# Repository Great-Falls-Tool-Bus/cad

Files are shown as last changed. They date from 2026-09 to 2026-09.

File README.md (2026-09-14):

# cad

GFTB shelving and related CAD drawings for the Great Falls Tool Bus.

## Layout

Follows the [VoronUsers](https://github.com/VoronDesign/VoronUsers) mods layout: one directory per creator, one per mod, each self-describing.

```
bus_mods/<creator>/<mod>/
├─ .metadata.yml     title, description, file manifest
├─ README.md         what it is, materials, images
├─ CAD/              source (.f3d) and neutral (.step) exports
├─ images/           renderings
├─ docs/             build sheets — LaTeX sources, compiled by Bazel
└─ pdfs/             the compiled build sheets, checked in so nobody needs a toolchain to read them
```

Index: [`bus_mods/README.md`](bus_mods/README.md).

## Building documents

Documents are LaTeX compiled with [rules_tectonic](https://github.com/Jesssullivan/rules_tectonic); no TeX install needed.

```sh
direnv allow                 # nix dev shell: bazelisk, tectonic, buildifier, uv
bazelisk build //:docs       # every PDF, or one target:
bazelisk build //bus_mods/jesssullivan/port_side_shelves/docs:cut_list
open bazel-bin/bus_mods/jesssullivan/port_side_shelves/docs/cut_list.pdf
```

After a doc changes, rebuild and copy the PDF into the mod's `pdfs/` so the checked-in copy matches its source.

`bazelisk run //:buildifier.check` lints the BUILD files.

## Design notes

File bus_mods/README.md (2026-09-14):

# Bus mods

| Creator | Mod | Description | Vehicle | Last changed |
| --- | --- | --- | --- | --- |
| jesssullivan | [Port-side shelves](jesssullivan/port_side_shelves) | Stick-framed 2×4 / 2×6 shelving with ⅜″ ply decks, three stepped bays | bus-hybrid | 2026-09-14 |

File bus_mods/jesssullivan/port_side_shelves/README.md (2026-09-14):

# Port-side shelves

Stick-framed shelving for the port (driver's) side of the Great Falls Tool Bus: 2×4 frames on 2×6 posts, decked with ⅜″ plywood. Three bays step up from a low 31″ entry step to a 72″-tall run, with the right-hand bay raised over the wheel arch. 175½″ long, 32″ deep, 72″ tall over the floor.

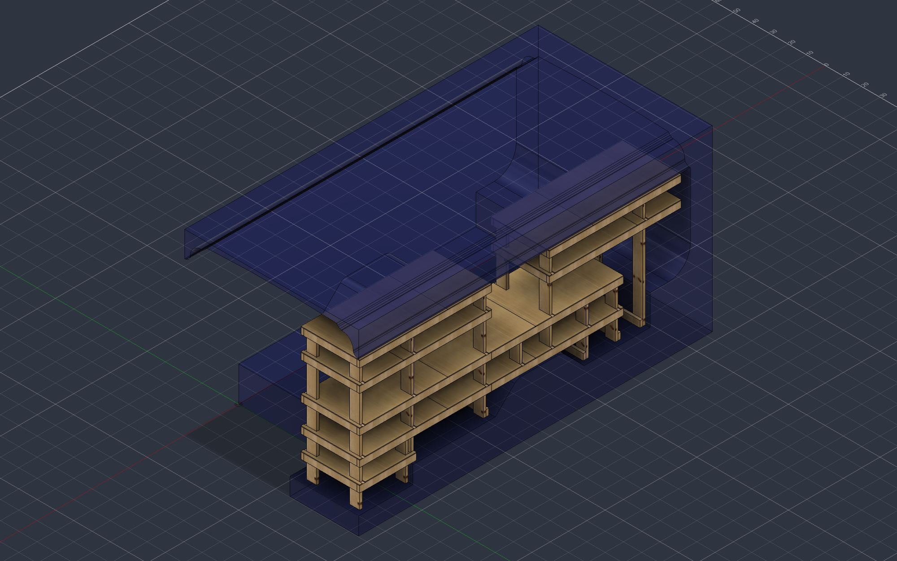
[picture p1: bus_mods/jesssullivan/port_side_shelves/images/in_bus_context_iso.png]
In the bus


## Materials

| Stock | Qty | Notes |
| --- | --- | --- |
| 2×4 × 8 ft | 34 | 16 × 72″ rails, 52 × 29″ cross members, 2 × 31″ rails |
| 2×6 × 8 ft | 10 | 18 posts in 6 lengths |
| ⅜″ plywood, 4×8 | 5 | 15 panels, all 32″ deep; 2 strips spare |

Full cut list with per-board patterns, sheet layouts and a dimensioned drawing of every unique plywood panel: [`pdfs/cut_list.pdf`](pdfs/cut_list.pdf), built from [`docs/cut_list.tex`](docs/cut_list.tex):

```sh
bazel build //bus_mods/jesssullivan/port_side_shelves/docs:cut_list
cp bazel-bin/bus_mods/jesssullivan/port_side_shelves/docs/cut_list.pdf bus_mods/jesssullivan/port_side_shelves/pdfs/
```
The stock plan is the exact cutting-stock optimum for 8-foot boards with ⅛″ kerf ([`docs/cutstock.py`](docs/cutstock.py)); the panel drawings are generated from the model ([`docs/ply_patterns.py`](docs/ply_patterns.py) over `docs/ply_outlines.json`, harvested via the Fusion MCP).

## CAD

| File | What |
| --- | --- |
| `CAD/bus_hybrid_assy.f3d` | Fusion archive of the whole design (bus body + shelves) |
| `CAD/port_side_shelves.step` | The shelving assembly only |

The Fusion tree is organised for reuse: 21 part components (one per cut length / plywood shape) placed inside frame sub-assemblies, and identical frames are one component placed several times — Bay A's z 31/46/78 frames are a single component ×3, Bay B's z 31/46 frames a single component ×2. Edit a frame once and every level that uses it follows.

```
Port Side Shelves (Assembly)
├─ Posts (2x6)                        18 posts · 6 part types
├─ Bay A – Left        x −28..44      Frame A z19 · Frame A z31/z46/z78 ×3 · Frame A z66
├─ Bay B – Center low  x 44..116      Frame B z31/z46 ×2
├─ Bay C – Right high  x 75½..147½    Frame C z66 · Frame C z78
├─ Floor cleats z19                   3 × 2x4 x 29″
└─ Decks (3/8 ply)                    z 22½ · 34½ · 49½ · 69½ · 81½
```

## Images

| | |
| --- | --- |
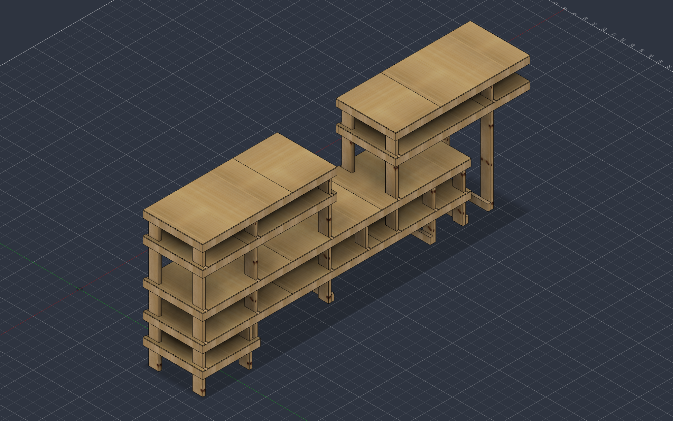
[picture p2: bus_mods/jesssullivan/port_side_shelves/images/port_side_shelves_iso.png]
iso
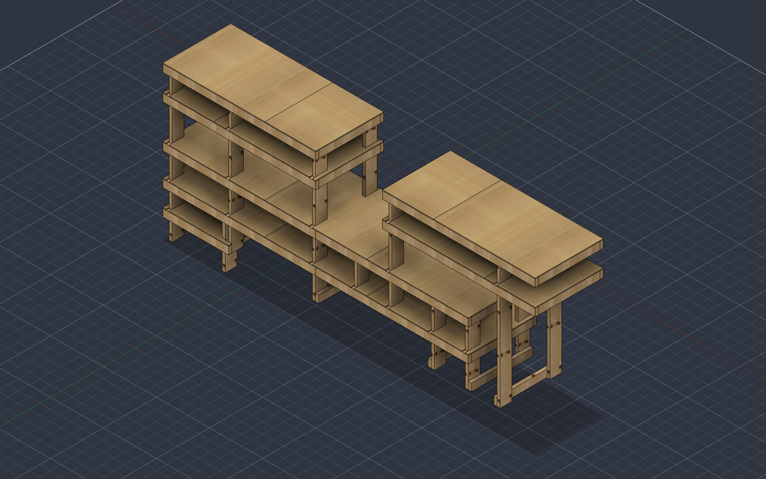
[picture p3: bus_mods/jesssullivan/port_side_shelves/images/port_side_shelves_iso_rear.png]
rear iso
|  |  |
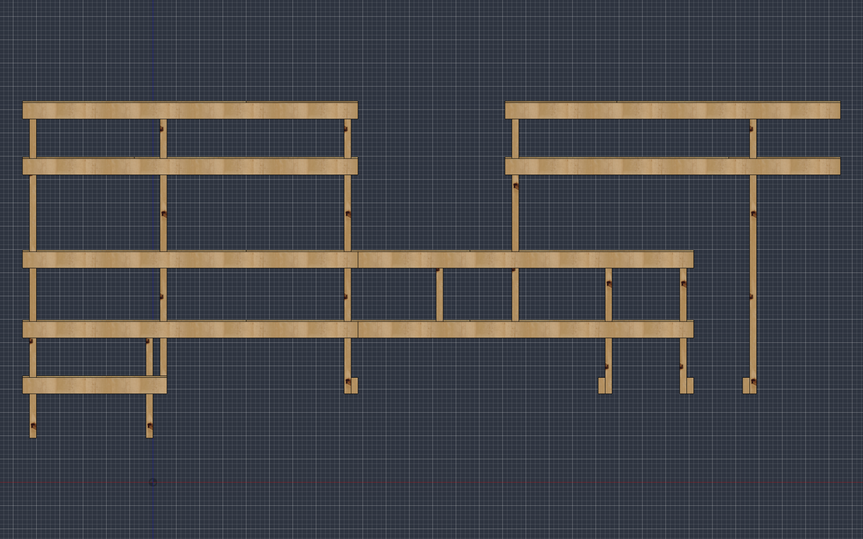
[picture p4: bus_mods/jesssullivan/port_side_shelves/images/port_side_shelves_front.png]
front
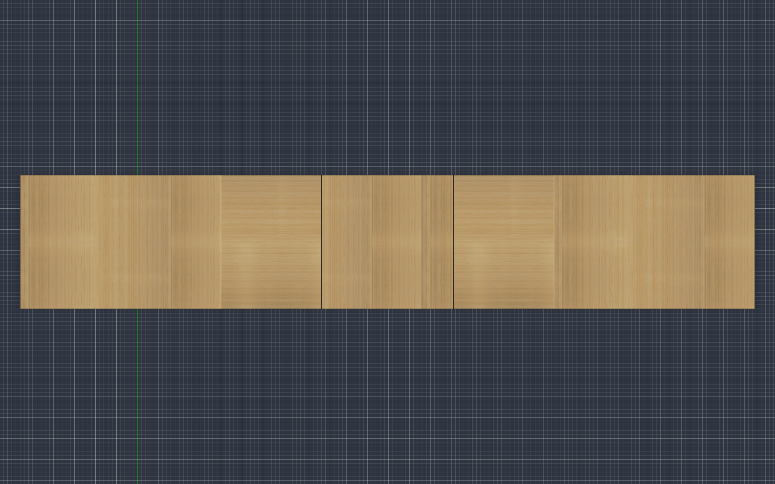
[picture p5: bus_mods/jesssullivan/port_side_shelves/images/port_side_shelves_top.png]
top
|  |  |

## Build notes

- Cross members are 29″ = 32″ depth − two 1½″ rails. Rails are 72″ per bay; the low step is the only 31″ bay.
- Plywood is crosscut into three 32 × 48 strips per sheet; two kerfs leave the third strip at 31¾″ — use those for the 24″ panels and the 31″ step so the ten full shelves stay full depth.
- Plywood notches are drawn with dimensions in the cut list (every unique panel); still check against the installed posts before cutting.
- The 16 × 24″ 2×4 offcuts from the 72″ rails aren't used by this design — nothing here is shorter than 29″.

Cheers,
-Jess

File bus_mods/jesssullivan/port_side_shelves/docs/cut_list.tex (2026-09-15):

% Port-side shelves — cut list / BOM
% Built with: bazel build //bus_mods/jesssullivan/port_side_shelves/docs:cut_list
% Source geometry: CAD/bus_hybrid_assy.f3d (Fusion), component "Port Side Shelves (Assembly)"
\documentclass[10pt,letterpaper]{article}
\usepackage[margin=0.7in,top=0.6in,bottom=0.7in]{geometry}
\usepackage[T1]{fontenc}
\usepackage{lmodern}
\usepackage[default]{sourcesanspro}
\usepackage{sourcecodepro}
\usepackage{booktabs}
\usepackage{array}
\usepackage{tabularx}
\usepackage{xcolor}
\usepackage{tikz}
\usepackage{enumitem}
\usepackage{fancyhdr}
\usepackage[hidelinks]{hyperref}

\definecolor{ink}{HTML}{1C222B}
\definecolor{ink2}{HTML}{4B535E}
\definecolor{rule}{HTML}{9AA09A}
\definecolor{pine}{HTML}{D9B97C}
\definecolor{pineink}{HTML}{3F3116}
\definecolor{ply}{HTML}{B98A55}
\definecolor{waste}{HTML}{D6D9CF}
\definecolor{accent}{HTML}{2456C9}

\pagestyle{fancy}
\fancyhf{}
\lhead{\small\textbf{GFTB} \textcolor{ink2}{· Bus-Hybrid-Assy · Port Side Shelves}}
\rhead{\small\textcolor{ink2}{cut list · rev 2026-09-14 · page \thepage}}
\renewcommand{\headrulewidth}{0.6pt}
\setlength{\parskip}{4pt}
\setlength{\parindent}{0pt}
\renewcommand{\arraystretch}{1.15}

% inches with fractions
\newcommand{\inch}[1]{#1\,in}
\newcommand{\lf}[1]{#1\,lf}
\newcommand{\kerf}{\tfrac{1}{8}}
\newcommand{\cutdim}[1]{\texttt{#1}}

% ---- cut-pattern bar: \cutbar{stock}{ {len1, len2, ...} }{label}
% scale: 1 in = 0.152 cm  ->  96 in = 14.6 cm
\newcommand{\barscale}{0.152}
\newcommand{\cutbar}[3]{%
  \begin{tikzpicture}[x=\barscale cm,y=1cm,baseline=(current bounding box.center)]
    \node[anchor=east,text width=2.6cm,align=right,font=\small\bfseries] at (-2,0.32) {#3};
    \fill[waste] (0,0) rectangle (#1,0.64);
    \draw[ink,line width=0.5pt] (0,0) rectangle (#1,0.64);
    \pgfmathsetmacro{\x}{0}
    \foreach \l in {#2} {%
      \fill[pine] (\x,0) rectangle (\x+\l,0.64);
      \draw[ink,line width=0.5pt] (\x,0) rectangle (\x+\l,0.64);
      \node[font=\footnotesize\ttfamily,text=pineink] at (\x+\l/2,0.32) {\l};
      \pgfmathsetmacro{\x}{\x+\l+0.125}
      \global\let\x\x
    }
  \end{tikzpicture}\par\vspace{2pt}}

\begin{document}

% ================= title block =================
\begin{tabularx}{\textwidth}{@{}X r@{}}
  {\fontsize{21}{23}\selectfont\bfseries PORT-SIDE SHELVES\newline CUT LIST} &
  \begin{tabular}[b]{@{}ll@{}}
    \textcolor{ink2}{\scriptsize SOURCE}   & \small Fusion · project \emph{Bus} · Bus-Hybrid-Assy \\
    \textcolor{ink2}{\scriptsize REVISION} & \small 2026-09-14, refactored tree \\
    \textcolor{ink2}{\scriptsize PARTS}    & \small 103 pieces · 21 unique \\
    \textcolor{ink2}{\scriptsize KERF}     & \small\ttfamily 1/8 in per cut \\
    \textcolor{ink2}{\scriptsize STOCK}    & \small 8 ft lumber · 4×8 ft sheets \\
    \textcolor{ink2}{\scriptsize ENVELOPE} & \small\ttfamily 175.5 × 32 × 72 in (L×D×H) \\
  \end{tabular}
\end{tabularx}
\vspace{2pt}\hrule height 1.2pt\vspace{6pt}
Every stick and sheet in the shelving unit, as a shopping list, per-board cut patterns, and the sub-assembly each part belongs to. Lengths are finished cut lengths in inches. Stock sizes are nominal; 2×4 is 1½~×~3½ actual, 2×6 is 1½~×~5½, all bought in 8-foot lengths.

\vspace{4pt}
\noindent\fbox{\parbox{\dimexpr\textwidth-2\fboxsep-2\fboxrule}{%
\textbf{If three shelves up instead of four} — removing the two topmost shelves (Bay A and Bay C at z\,81½, with their z\,78 frames) changes the buy to:
\begin{center}\small
\begin{tabularx}{\dimexpr\textwidth-2\fboxsep-2\fboxrule-8pt}{@{}l r r r X@{}}
\toprule
\textbf{Stock} & \textbf{4 shelves} & \textbf{3 shelves} & \textbf{Fewer to buy} & \textbf{What drops out} \\
\midrule
2×4 × 8 ft & 34 & 27 & \textbf{−7} & 4 × 72 rails and 10 × 29 cross members; patterns become 12 → 72, 14 → 29+29+29, 1 → 31+31 \\
2×6 × 8 ft & 10 & 10 & \textbf{0} & nothing — leave the posts full height for a later top deck, or cut them 12 in shorter; the board count is the same either way \\
⅜ in plywood, 4×8 & 5 & 4 & \textbf{−1} & 2 × 32×48 and 2 × 24×32; 10 strips from 4 sheets, 2 spare \\
\bottomrule
\end{tabularx}
\end{center}
Everything below is the four-shelf build.}}

% ================= shopping list =================
\section*{Shopping list}
\begin{tabularx}{\textwidth}{@{}l r X r r@{}}
\toprule
\textbf{Stock} & \textbf{Buy} & \textbf{Makes} & \textbf{Net} & \textbf{Waste} \\
\midrule
2×4 × 8 ft      & \textbf{34} & 16 × 72 rails · 52 × 29 cross members · 2 × 31 rails & \lf{226.8} & 16.6\,\% \\
2×6 × 8 ft      & \textbf{10} & 18 posts in 6 lengths (72, 62½, 50½, 30½, 25, 18½) & \lf{69.1} & 13.6\,\% \\
⅜ in plywood, 4×8 & \textbf{5} & 10 × 32×48 · 4 × 24×32 · 1 × 31×32 (2 strips spare) & 4.22 sheets & 15.6\,\% \\
\bottomrule
\end{tabularx}

\textcolor{ink2}{\small Waste on the 2×4s is almost entirely the 24-inch offcut left when a 72-inch rail comes out of an 8-footer (16 of them = 32 ft). Nothing in the design is shorter than 29 in, so they can't be reused here; keep them for blocking.}

% ================= 2x4 =================
\section*{2×4 — frames (34 boards)}
\begin{minipage}[t]{0.46\textwidth}
\begin{tabular}{@{}l r l@{}}
\toprule
\textbf{Cut} & \textbf{Qty} & \textbf{Used as} \\
\midrule
\cutdim{72}  & 16 & front/back rails, 8 frames × 2 \\
\cutdim{29}  & 52 & cross members, 49 in frames + 3 floor cleats \\
\cutdim{31}  &  2 & rails, low-step frame \\
\midrule
net & 70 & \cutdim{2722 in = 226.8 lf} \\
\bottomrule
\end{tabular}
\end{minipage}\hfill
\begin{minipage}[t]{0.50\textwidth}
\small Cross members are 29 in because the unit is 32 in deep and the rails are 1½ in thick each. Rails are 72 in because every bay is 72 in long; the low step at the left end is the only 31-inch bay.
\end{minipage}

\subsection*{Cut patterns}
\cutbar{96}{72}{16 × 8 ft}
\cutbar{96}{29,29,29}{17 × 8 ft}
\cutbar{96}{31,31,29}{1 × 8 ft}
{\footnotesize\textcolor{ink2}{Bars to scale · shaded end is offcut: 24 in, 8¾ in, 4¾ in · kerf not drawn}}

% ================= 2x6 =================
\section*{2×6 — posts (10 boards)}
\begin{minipage}[t]{0.46\textwidth}
\begin{tabular}{@{}l r l@{}}
\toprule
\textbf{Cut} & \textbf{Qty} & \textbf{Where} \\
\midrule
\cutdim{72}   & 2 & Bay A left end, floor (z 9½) to top \\
\cutdim{62.5} & 6 & full-height posts, x 1½ / 41 / 128 \\
\cutdim{50.5} & 2 & Bay C posts off the z 31 frame, x 77 \\
\cutdim{30.5} & 4 & Bay B lower posts, x 97 / 113 \\
\cutdim{25}   & 2 & low-step posts, x −1½ \\
\cutdim{18.5} & 2 & Bay B short posts, x 60¾ \\
\midrule
net & 18 & \cutdim{829 in = 69.1 lf} \\
\bottomrule
\end{tabular}
\end{minipage}\hfill
\begin{minipage}[t]{0.50\textwidth}
\small Posts go front and back in pairs (y −92½ and y −69), so every length above is an even count. x positions are inches from the design origin; z is height above the design origin, floor of the shelving is z 19 except the two 72-inch corner posts and the low step, which reach down to z 9½.
\end{minipage}

\subsection*{Cut patterns}
\cutbar{96}{62.5,30.5}{4 × 8 ft}
\cutbar{96}{62.5,25}{2 × 8 ft}
\cutbar{96}{72,18.5}{2 × 8 ft}
\cutbar{96}{50.5,25,18.5}{2 × 8 ft}
{\footnotesize\textcolor{ink2}{Offcuts: 2⅞, 8⅜, 5⅜, 1¾ in. The 50½ + 25 + 18½ board leaves only 1¾ in — check that board is a full 96 before cutting.}}

% ================= plywood =================
\section*{⅜ in plywood — 15 panels from 5 sheets}
Crosscut each 4×8 sheet across its length into three 32~×~48 strips (cuts at 32 and 64). Ten strips go up as-is; two are halved into 24~×~32; one is trimmed to 31~×~32 for the low step. Two strips are spare.

\begin{center}
\begin{tikzpicture}[x=0.088cm,y=0.088cm]
  % sheet 1-3
  \begin{scope}
    \fill[ply] (0,0) rectangle (96,48); \draw[ink] (0,0) rectangle (96,48);
    \draw[ink] (32,0)--(32,48) (64,0)--(64,48);
    \foreach \x in {16,48,80} { \node[font=\small\bfseries,text=white] at (\x,24) {32×48}; }
    \node[anchor=south west,font=\footnotesize\bfseries] at (0,49) {Sheets 1–3 (×3)};
  \end{scope}
  % sheet 4
  \begin{scope}[xshift=9.3cm]
    \fill[ply] (0,0) rectangle (96,48); \draw[ink] (0,0) rectangle (96,48);
    \draw[ink] (32,0)--(32,48) (64,0)--(64,48);
    \draw[ink] (32,24)--(96,24);
    \node[font=\small\bfseries,text=white] at (16,24) {32×48};
    \foreach \x in {48,80} { \node[font=\small\bfseries,text=white] at (\x,36) {24×32}; \node[font=\small\bfseries,text=white] at (\x,12) {24×32}; }
    \node[anchor=south west,font=\footnotesize\bfseries] at (0,49) {Sheet 4};
  \end{scope}
  % sheet 5
  \begin{scope}[yshift=-5.3cm]
    \fill[ply] (0,0) rectangle (96,48); \draw[ink] (0,0) rectangle (96,48);
    \draw[ink] (32,0)--(32,48) (64,0)--(64,48);
    \fill[waste] (0,0) rectangle (32,17); \draw[ink] (0,17)--(32,17);
    \node[font=\small\bfseries,text=white] at (16,32) {31×32};
    \node[font=\scriptsize,text=ink2] at (16,8) {offcut 17×32};
    \foreach \x in {48,80} { \draw[ink,dashed] (\x-16,0) rectangle (\x+16,48); \node[font=\small,text=white] at (\x,24) {spare}; }
    \node[anchor=south west,font=\footnotesize\bfseries] at (0,49) {Sheet 5};
  \end{scope}
\end{tikzpicture}
\end{center}

\begin{tabularx}{\textwidth}{@{}l r X X@{}}
\toprule
\textbf{Panel} & \textbf{Qty} & \textbf{Deck (z = top of frame)} & \textbf{Notches} \\
\midrule
\cutdim{32 × 48} &  2 & z 81½ top, Bay A and Bay C & none \\
\cutdim{32 × 48} &  8 & z 34½ ×3 · z 49½ ×3 · z 69½ ×2 & post notches, 7 patterns (A–G), drawn below \\
\cutdim{24 × 32} &  2 & z 81½ top & none \\
\cutdim{24 × 32} &  2 & z 69½, ends of Bay A / Bay C & post notches (A, B), drawn below \\
\cutdim{31 × 32} &  1 & z 22½ low step & post notches \\
\midrule
net & 15 & \multicolumn{2}{l}{\cutdim{19,424 in² = 4.22 sheets → 5}} \\
\bottomrule
\end{tabularx}

\subsection*{Panel patterns}
Every unique panel outline, read from the model. Notch callouts are \cutdim{offset + width} from the panel's left edge (as installed, looking down); front-edge notches are labelled below the panel, back-edge above. All notches are 7~in deep unless the panel says otherwise. Mark them from these dimensions, then check against the installed posts before cutting.

\noindent\input{ply_patterns.tex}

% ================= assembly =================
\section*{How the parts are grouped in Fusion}
Same 103 bodies, now as 21 reusable part components inside reusable frames (42 components total, down from 104). Identical frames are one component placed more than once, so editing a frame edits every level that uses it.

{\small\begin{verbatim}
Port Side Shelves (Assembly)
  Posts (2x6)                                   18 posts, 6 part types
  Bay A - Left, x -28..44
    Frame A z19          (31 in rails, 3 cross)   x1
    Frame A z31/z46/z78  (72 in rails, 5 cross)   x3  <- one component
    Frame A z66          (72 in rails, 6 cross)   x1
  Bay B - Center lower, x 44..116
    Frame B z31/z46      (72 in rails, 7 cross)   x2  <- one component
  Bay C - Right upper, x 75.5..147.5
    Frame C z66          (72 in rails, 6 cross)   x1
    Frame C z78          (72 in rails, 5 cross)   x1
  Floor cleats z19 (2x4)                        3 x 29 in
  Decks (3/8 ply)                               z 22.5 (1)  34.5 (3)  49.5 (3)  69.5 (4)  81.5 (4)
\end{verbatim}}

\end{document}

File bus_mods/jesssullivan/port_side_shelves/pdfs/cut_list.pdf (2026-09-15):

GFTB · Bus‑Hybrid‑Assy · Port Side Shelves | cut list · rev 2026‑09‑14 · page 1

# PORT‑SIDE SHELVES CUT LIST

SOURCE | Fusion · project Bus · Bus‑Hybrid‑Assy
REVISION | 2026‑09‑14, refactored tree
PARTS | 103 pieces · 21 unique
KERF | 1/8 in per cut
STOCK | 8 ft lumber · 4×8 ft sheets
ENVELOPE | 175.5 × 32 × 72 in (L×D×H)

Every stick and sheet in the shelving unit, as a shopping list, per‑board cut patterns, and the sub‑assembly each part belongs to. Lengths are finished cut lengths in inches. Stock sizes are nominal; 2×4 is 1½ × 3½ actual, 2×6 is 1½ × 5½, all bought in 8‑foot lengths.
If three shelves up instead of four — removing the two topmost shelves (Bay A and Bay C at z 81½, with their z 78 frames) changes the buy to:
Stock | 4 shelves 3 shelves Fewer to buy What drops out
2×4 × 8 ft | 34 | 27 | −7 4 × 72 rails and 10 × 29 cross members; patterns become 12 → 72, 14 →
29+29+29, 1 → 31+31
2×6 × 8 ft | 10 | 10 | 0 nothing — leave the posts full height for a later top deck, or cut them
12 in shorter; the board count is the same either way
⅜ in plywood, 4×8 | 5 | 4 | −1 2 × 32×48 and 2 × 24×32; 10 strips from 4 sheets, 2 spare
Everything below is the four‑shelf build.

## Shopping list

Stock | Buy Makes | Net Waste
2×4 × 8 ft | 34 16 × 72 rails · 52 × 29 cross members · 2 × 31 rails | 226.8 lf 16.6 %
2×6 × 8 ft | 10 18 posts in 6 lengths (72, 62½, 50½, 30½, 25, 18½) | 69.1 lf 13.6 %
⅜ in plywood, 4×8 | 5 10 × 32×48 · 4 × 24×32 · 1 × 31×32 (2 strips spare) | 4.22 sheets 15.6 %
Waste on the 2×4s is almost entirely the 24‑inch offcut left when a 72‑inch rail comes out of an 8‑footer (16 of them = 32 ft). Nothing in the design is shorter than 29 in, so they can’t be reused here; keep them for blocking.

## 2×4 — frames (34 boards)

Cut Qty Used as
72 | 16 front/back rails, 8 frames × 2
29 | 52 cross members, 49 in frames + 3 floor cleats
31 | 2 rails, low‑step frame
net | 70 2722 in = 226.8 lf

Cross members are 29 in because the unit is 32 in deep and the rails are 1½ in thick each. Rails are 72 in because every bay is 72 in long; the low step at the left end is the only 31‑inch bay.

### Cut patterns

16 × 8 ft | 72
17 × 8 ft | 29 | 29 | 29
1 × 8 ft | 31 | 31 | 29

GFTB · Bus‑Hybrid‑Assy · Port Side Shelves | cut list · rev 2026‑09‑14 · page 2

Bars to scale · shaded end is offcut: 24 in, 8¾ in, 4¾ in · kerf not drawn

## 2×6 — posts (10 boards)

Cut | Qty Where
72 | 2 Bay A left end, floor (z 9½) to top
62.5 | 6 full‑height posts, x 1½ / 41 / 128
50.5 | 2 Bay C posts off the z 31 frame, x 77
30.5 | 4 Bay B lower posts, x 97 / 113
25 | 2 low‑step posts, x −1½
18.5 | 2 Bay B short posts, x 60¾
net | 18 829 in = 69.1 lf

Posts go front and back in pairs (y −92½ and y −69), so every length above is an even count. x positions are inches from the design origin; z is height above the design origin, floor of the shelving is z 19 except the two 72‑inch corner posts and the low step, which reach down to z 9½.

### Cut patterns

4 × 8 ft | 62.5 | 30.5
2 × 8 ft | 62.5 | 25
2 × 8 ft | 72 | 18.5
2 × 8 ft | 50.5 | 25 | 18.5

Offcuts: 2⅞, 8⅜, 5⅜, 1¾ in. The 50½ + 25 + 18½ board leaves only 1¾ in — check that board is a full 96 before cutting.

## ⅜ in plywood — 15 panels from 5 sheets

Crosscut each 4×8 sheet across its length into three 32 × 48 strips (cuts at 32 and 64). Ten strips go up as‑is; two are halved into 24 × 32; one is trimmed to 31 × 32 for the low step. Two strips are spare.

GFTB · Bus‑Hybrid‑Assy · Port Side Shelves | cut list · rev 2026‑09‑14 · page 3
32×48 | 32×48 | 32×48

Sheets 1–3 (×3)

32×48

24×32

24×32

24×32

24×32

Sheet 4

31×32

offcut 17×32

spare | spare

Sheet 5

Panel | Qty Deck (z = top of frame) | Notches
32 × 48 | 2 z 81½ top, Bay A and Bay C | none
32 × 48 | 8 z 34½ ×3 · z 49½ ×3 · z 69½ ×2 | post notches, 7 patterns (A–G), drawn below
24 × 32 | 2 z 81½ top | none
24 × 32 | 2 z 69½, ends of Bay A / Bay C | post notches (A, B), drawn below
31 × 32 | 1 z 22½ low step | post notches
net | 15 19,424 in² = 4.22 sheets → 5

### Panel patterns

Every unique panel outline, read from the model. Notch callouts are offset + width from the panel’s left edge (as installed, looking down); front‑edge notches are labelled below the panel, back‑edge above. All notches are 7 in deep unless the panel says otherwise. Mark them from these dimensions, then check against the installed posts before cutting.
| 32 x 48 ×2

48

32

z 81½ @ x ‑28 · z 81½ @ x 99½

### 32 x 48 · notch A ×1

48

32

1½ + 1½

1½ + 1½

notches 7 in deep

z 69½ @ x 75½

### 32 x 48 · notch B ×1

48

32

9 + 1½

9 + 1½

notches 7 in deep

z 49½ @ x 68

GFTB · Bus‑Hybrid‑Assy · Port Side Shelves | cut list · rev 2026‑09‑14 · page 4

### 32 x 48 · notch C ×1

48

32

21 + 1½

21 + 1½

notches 7 in deep

z 49½ @ x 20

### 32 x 48 · notch D ×2

48

32

1½ + 1½ | 29½ + 1½
1½ + 1½ | 29½ + 1½

notches 7 in deep

z 34½ @ x ‑28 · z 49½ @ x ‑28

### 32 x 48 · notch E ×1

48

32

5½ + 1½ | 45 + 1½
5½ + 1½ | 45 + 1½

notches 7 in deep

z 69½ @ x ‑4

### 32 x 48 · notch F ×1

48

32

21 + 1½ | 40¾ + 1½
21 + 1½ | 40¾ + 1½

notches 7 in deep

z 34½ @ x 20

### 32 x 48 · notch G ×1

48

32

9 + 1½ | 29 + 1½ | 45 + 1½
9 + 1½ | 29 + 1½ | 45 + 1½

notches 7 in deep

z 34½ @ x 68

### 31 x 32 · notch A ×1

31

32

1½ + 1½ | 26½ + 4½
1½ + 1½ | 26½ + 4½

notches 7 in deep

z 22½ @ x ‑28

### 24 x 32 ×2

24

32

z 81½ @ x 20 · z 81½ @ x 75½

### 24 x 32 · notch A ×1

24

32

1½ + 1½

1½ + 1½

notches 7 in deep

z 69½ @ x ‑28

### 24 x 32 · notch B ×1

24

32

4½ + 1½

4½ + 1½

notches 7 in deep

z 69½ @ x 123½

## How the parts are grouped in Fusion

Same 103 bodies, now as 21 reusable part components inside reusable frames (42 components total, down from 104). Iden‑ tical frames are one component placed more than once, so editing a frame edits every level that uses it.

Port Side Shelves (Assembly)
Posts (2x6) | 18 posts, 6 part types
Bay A - Left, x -28..44
Frame A z19 | (31 in rails, 3 cross) | x1
Frame A z31/z46/z78 | (72 in rails, 5 cross) | x3 | <- one component
Frame A z66 | (72 in rails, 6 cross) | x1
Bay B - Center lower, x 44..116
Frame B z31/z46 | (72 in rails, 7 cross) | x2 <- one component
Bay C - Right upper, x 75.5..147.5
Frame C z66 | (72 in rails, 6 cross) | x1
Frame C z78 | (72 in rails, 5 cross) | x1
Floor cleats z19 (2x4) | 3 x 29 in
Decks (3/8 ply) | z 22.5 (1) 34.5 (3) 49.5 (3) 69.5 (4) 81.5 (4)

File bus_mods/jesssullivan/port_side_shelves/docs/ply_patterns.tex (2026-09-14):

% generated from ply_outlines.json by ply_patterns.py — do not hand-edit
\begin{minipage}[t]{0.33\textwidth}\centering
{\small\bfseries 32 x 48}\quad{\footnotesize\textcolor{ink2}{×2}}\\[2pt]
\begin{tikzpicture}[x=0.105cm,y=0.105cm,baseline]
  \fill[ply] (0.0,0.0) -- (0.0,32.0) -- (48.0,32.0) -- (48.0,0.0) -- cycle;
  \draw[ink,line width=0.5pt] (0.0,0.0) -- (0.0,32.0) -- (48.0,32.0) -- (48.0,0.0) -- cycle;
  \draw[ink2,|-|,line width=0.3pt] (0,-3.2) -- (48.0,-3.2) node[midway,below,font=\scriptsize\ttfamily,text=ink] {48};
  \draw[ink2,|-|,line width=0.3pt] (48.0+3.2,0) -- (48.0+3.2,32.0) node[midway,right,font=\scriptsize\ttfamily,text=ink] {32};
\end{tikzpicture}\\[1pt]
{\scriptsize\textcolor{ink2}{z\,81½ @ x\,-28 · z\,81½ @ x\,99½}}
\end{minipage}
\begin{minipage}[t]{0.33\textwidth}\centering
{\small\bfseries 32 x 48 · notch A}\quad{\footnotesize\textcolor{ink2}{×1}}\\[2pt]
\begin{tikzpicture}[x=0.105cm,y=0.105cm,baseline]
  \fill[ply] (1.5,-0.0) -- (1.5,7.0) -- (3.0,7.0) -- (3.0,-0.0) -- (48.0,0.0) -- (48.0,32.0) -- (3.0,32.0) -- (3.0,25.0) -- (1.5,25.0) -- (1.5,32.0) -- (0.0,32.0) -- (0.0,0.0) -- cycle;
  \draw[ink,line width=0.5pt] (1.5,-0.0) -- (1.5,7.0) -- (3.0,7.0) -- (3.0,-0.0) -- (48.0,0.0) -- (48.0,32.0) -- (3.0,32.0) -- (3.0,25.0) -- (1.5,25.0) -- (1.5,32.0) -- (0.0,32.0) -- (0.0,0.0) -- cycle;
  \draw[ink2,|-|,line width=0.3pt] (0,-3.2) -- (48.0,-3.2) node[midway,below,font=\scriptsize\ttfamily,text=ink] {48};
  \draw[ink2,|-|,line width=0.3pt] (48.0+3.2,0) -- (48.0+3.2,32.0) node[midway,right,font=\scriptsize\ttfamily,text=ink] {32};
  \node[font=\tiny\ttfamily,text=ink,below=-2pt] at (2.25,-1.3) {1½\,+\,1½};
  \node[font=\tiny\ttfamily,text=ink,above=-2pt] at (2.25,33.3) {1½\,+\,1½};
  \node[font=\tiny,text=ink2] at (24.0,16.0) {notches 7 in deep};
\end{tikzpicture}\\[1pt]
{\scriptsize\textcolor{ink2}{z\,69½ @ x\,75½}}
\end{minipage}
\begin{minipage}[t]{0.33\textwidth}\centering
{\small\bfseries 32 x 48 · notch B}\quad{\footnotesize\textcolor{ink2}{×1}}\\[2pt]
\begin{tikzpicture}[x=0.105cm,y=0.105cm,baseline]
  \fill[ply] (10.5,32.0) -- (10.5,25.0) -- (9.0,25.0) -- (9.0,32.0) -- (0.0,32.0) -- (0.0,0.0) -- (9.0,-0.0) -- (9.0,7.0) -- (10.5,7.0) -- (10.5,-0.0) -- (48.0,-0.0) -- (48.0,32.0) -- cycle;
  \draw[ink,line width=0.5pt] (10.5,32.0) -- (10.5,25.0) -- (9.0,25.0) -- (9.0,32.0) -- (0.0,32.0) -- (0.0,0.0) -- (9.0,-0.0) -- (9.0,7.0) -- (10.5,7.0) -- (10.5,-0.0) -- (48.0,-0.0) -- (48.0,32.0) -- cycle;
  \draw[ink2,|-|,line width=0.3pt] (0,-3.2) -- (48.0,-3.2) node[midway,below,font=\scriptsize\ttfamily,text=ink] {48};
  \draw[ink2,|-|,line width=0.3pt] (48.0+3.2,0) -- (48.0+3.2,32.0) node[midway,right,font=\scriptsize\ttfamily,text=ink] {32};
  \node[font=\tiny\ttfamily,text=ink,below=-2pt] at (9.75,-1.3) {9\,+\,1½};
  \node[font=\tiny\ttfamily,text=ink,above=-2pt] at (9.75,33.3) {9\,+\,1½};
  \node[font=\tiny,text=ink2] at (24.0,16.0) {notches 7 in deep};
\end{tikzpicture}\\[1pt]
{\scriptsize\textcolor{ink2}{z\,49½ @ x\,68}}
\end{minipage}
\begin{minipage}[t]{0.33\textwidth}\centering
{\small\bfseries 32 x 48 · notch C}\quad{\footnotesize\textcolor{ink2}{×1}}\\[2pt]
\begin{tikzpicture}[x=0.105cm,y=0.105cm,baseline]
  \fill[ply] (22.5,32.0) -- (22.5,25.0) -- (21.0,25.0) -- (21.0,32.0) -- (0.0,32.0) -- (-0.0,0.0) -- (21.0,0.0) -- (21.0,7.0) -- (22.5,7.0) -- (22.5,0.0) -- (48.0,0.0) -- (48.0,32.0) -- cycle;
  \draw[ink,line width=0.5pt] (22.5,32.0) -- (22.5,25.0) -- (21.0,25.0) -- (21.0,32.0) -- (0.0,32.0) -- (-0.0,0.0) -- (21.0,0.0) -- (21.0,7.0) -- (22.5,7.0) -- (22.5,0.0) -- (48.0,0.0) -- (48.0,32.0) -- cycle;
  \draw[ink2,|-|,line width=0.3pt] (0,-3.2) -- (48.0,-3.2) node[midway,below,font=\scriptsize\ttfamily,text=ink] {48};
  \draw[ink2,|-|,line width=0.3pt] (48.0+3.2,0) -- (48.0+3.2,32.0) node[midway,right,font=\scriptsize\ttfamily,text=ink] {32};
  \node[font=\tiny\ttfamily,text=ink,below=-2pt] at (21.75,-1.3) {21\,+\,1½};
  \node[font=\tiny\ttfamily,text=ink,above=-2pt] at (21.75,33.3) {21\,+\,1½};
  \node[font=\tiny,text=ink2] at (24.0,16.0) {notches 7 in deep};
\end{tikzpicture}\\[1pt]
{\scriptsize\textcolor{ink2}{z\,49½ @ x\,20}}
\end{minipage}
\begin{minipage}[t]{0.33\textwidth}\centering
{\small\bfseries 32 x 48 · notch D}\quad{\footnotesize\textcolor{ink2}{×2}}\\[2pt]
\begin{tikzpicture}[x=0.105cm,y=0.105cm,baseline]
  \fill[ply] (31.0,32.0) -- (31.0,25.0) -- (29.5,25.0) -- (29.5,32.0) -- (3.0,32.0) -- (3.0,25.0) -- (1.5,25.0) -- (1.5,32.0) -- (0.0,32.0) -- (0.0,0.0) -- (1.5,0.0) -- (1.5,7.0) -- (3.0,7.0) -- (3.0,0.0) -- (29.5,0.0) -- (29.5,7.0) -- (31.0,7.0) -- (31.0,0.0) -- (48.0,0.0) -- (48.0,32.0) -- cycle;
  \draw[ink,line width=0.5pt] (31.0,32.0) -- (31.0,25.0) -- (29.5,25.0) -- (29.5,32.0) -- (3.0,32.0) -- (3.0,25.0) -- (1.5,25.0) -- (1.5,32.0) -- (0.0,32.0) -- (0.0,0.0) -- (1.5,0.0) -- (1.5,7.0) -- (3.0,7.0) -- (3.0,0.0) -- (29.5,0.0) -- (29.5,7.0) -- (31.0,7.0) -- (31.0,0.0) -- (48.0,0.0) -- (48.0,32.0) -- cycle;
  \draw[ink2,|-|,line width=0.3pt] (0,-3.2) -- (48.0,-3.2) node[midway,below,font=\scriptsize\ttfamily,text=ink] {48};
  \draw[ink2,|-|,line width=0.3pt] (48.0+3.2,0) -- (48.0+3.2,32.0) node[midway,right,font=\scriptsize\ttfamily,text=ink] {32};
  \node[font=\tiny\ttfamily,text=ink,below=-2pt] at (2.25,-1.3) {1½\,+\,1½};
  \node[font=\tiny\ttfamily,text=ink,below=-2pt] at (30.25,-1.3) {29½\,+\,1½};
  \node[font=\tiny\ttfamily,text=ink,above=-2pt] at (2.25,33.3) {1½\,+\,1½};
  \node[font=\tiny\ttfamily,text=ink,above=-2pt] at (30.25,33.3) {29½\,+\,1½};
  \node[font=\tiny,text=ink2] at (24.0,16.0) {notches 7 in deep};
\end{tikzpicture}\\[1pt]
{\scriptsize\textcolor{ink2}{z\,34½ @ x\,-28 · z\,49½ @ x\,-28}}
\end{minipage}
\begin{minipage}[t]{0.33\textwidth}\centering
{\small\bfseries 32 x 48 · notch E}\quad{\footnotesize\textcolor{ink2}{×1}}\\[2pt]
\begin{tikzpicture}[x=0.105cm,y=0.105cm,baseline]
  \fill[ply] (45.0,-0.0) -- (45.0,7.0) -- (46.5,7.0) -- (46.5,0.0) -- (48.0,0.0) -- (48.0,32.0) -- (46.5,32.0) -- (46.5,25.0) -- (45.0,25.0) -- (45.0,32.0) -- (7.0,32.0) -- (7.0,25.0) -- (5.5,25.0) -- (5.5,32.0) -- (0.0,32.0) -- (0.0,0.0) -- (5.5,0.0) -- (5.5,7.0) -- (7.0,7.0) -- (7.0,0.0) -- cycle;
  \draw[ink,line width=0.5pt] (45.0,-0.0) -- (45.0,7.0) -- (46.5,7.0) -- (46.5,0.0) -- (48.0,0.0) -- (48.0,32.0) -- (46.5,32.0) -- (46.5,25.0) -- (45.0,25.0) -- (45.0,32.0) -- (7.0,32.0) -- (7.0,25.0) -- (5.5,25.0) -- (5.5,32.0) -- (0.0,32.0) -- (0.0,0.0) -- (5.5,0.0) -- (5.5,7.0) -- (7.0,7.0) -- (7.0,0.0) -- cycle;
  \draw[ink2,|-|,line width=0.3pt] (0,-3.2) -- (48.0,-3.2) node[midway,below,font=\scriptsize\ttfamily,text=ink] {48};
  \draw[ink2,|-|,line width=0.3pt] (48.0+3.2,0) -- (48.0+3.2,32.0) node[midway,right,font=\scriptsize\ttfamily,text=ink] {32};
  \node[font=\tiny\ttfamily,text=ink,below=-2pt] at (6.25,-1.3) {5½\,+\,1½};
  \node[font=\tiny\ttfamily,text=ink,below=-2pt] at (45.75,-1.3) {45\,+\,1½};
  \node[font=\tiny\ttfamily,text=ink,above=-2pt] at (6.25,33.3) {5½\,+\,1½};
  \node[font=\tiny\ttfamily,text=ink,above=-2pt] at (45.75,33.3) {45\,+\,1½};
  \node[font=\tiny,text=ink2] at (24.0,16.0) {notches 7 in deep};
\end{tikzpicture}\\[1pt]
{\scriptsize\textcolor{ink2}{z\,69½ @ x\,-4}}
\end{minipage}
\begin{minipage}[t]{0.33\textwidth}\centering
{\small\bfseries 32 x 48 · notch F}\quad{\footnotesize\textcolor{ink2}{×1}}\\[2pt]
\begin{tikzpicture}[x=0.105cm,y=0.105cm,baseline]
  \fill[ply] (21.0,25.0) -- (21.0,32.0) -- (0.0,32.0) -- (0.0,0.0) -- (21.0,0.0) -- (21.0,7.0) -- (22.5,7.0) -- (22.5,0.0) -- (40.75,0.0) -- (40.75,7.0) -- (42.25,7.0) -- (42.25,0.0) -- (48.0,0.0) -- (48.0,32.0) -- (42.25,32.0) -- (42.25,25.0) -- (40.75,25.0) -- (40.75,32.0) -- (22.5,32.0) -- (22.5,25.0) -- cycle;
  \draw[ink,line width=0.5pt] (21.0,25.0) -- (21.0,32.0) -- (0.0,32.0) -- (0.0,0.0) -- (21.0,0.0) -- (21.0,7.0) -- (22.5,7.0) -- (22.5,0.0) -- (40.75,0.0) -- (40.75,7.0) -- (42.25,7.0) -- (42.25,0.0) -- (48.0,0.0) -- (48.0,32.0) -- (42.25,32.0) -- (42.25,25.0) -- (40.75,25.0) -- (40.75,32.0) -- (22.5,32.0) -- (22.5,25.0) -- cycle;
  \draw[ink2,|-|,line width=0.3pt] (0,-3.2) -- (48.0,-3.2) node[midway,below,font=\scriptsize\ttfamily,text=ink] {48};
  \draw[ink2,|-|,line width=0.3pt] (48.0+3.2,0) -- (48.0+3.2,32.0) node[midway,right,font=\scriptsize\ttfamily,text=ink] {32};
  \node[font=\tiny\ttfamily,text=ink,below=-2pt] at (21.75,-1.3) {21\,+\,1½};
  \node[font=\tiny\ttfamily,text=ink,below=-2pt] at (41.5,-1.3) {40¾\,+\,1½};
  \node[font=\tiny\ttfamily,text=ink,above=-2pt] at (21.75,33.3) {21\,+\,1½};
  \node[font=\tiny\ttfamily,text=ink,above=-2pt] at (41.5,33.3) {40¾\,+\,1½};
  \node[font=\tiny,text=ink2] at (24.0,16.0) {notches 7 in deep};
\end{tikzpicture}\\[1pt]
{\scriptsize\textcolor{ink2}{z\,34½ @ x\,20}}
\end{minipage}
\begin{minipage}[t]{0.33\textwidth}\centering
{\small\bfseries 32 x 48 · notch G}\quad{\footnotesize\textcolor{ink2}{×1}}\\[2pt]
\begin{tikzpicture}[x=0.105cm,y=0.105cm,baseline]
  \fill[ply] (9.0,25.0) -- (9.0,32.0) -- (0.0,32.0) -- (0.0,0.0) -- (9.0,0.0) -- (9.0,7.0) -- (10.5,7.0) -- (10.5,0.0) -- (29.0,-0.0) -- (29.0,7.0) -- (30.5,7.0) -- (30.5,-0.0) -- (45.0,-0.0) -- (45.0,7.0) -- (46.5,7.0) -- (46.5,-0.0) -- (48.0,0.0) -- (48.0,32.0) -- (46.5,32.0) -- (46.5,25.0) -- (45.0,25.0) -- (45.0,32.0) -- (30.5,32.0) -- (30.5,25.0) -- (29.0,25.0) -- (29.0,32.0) -- (10.5,32.0) -- (10.5,25.0) -- cycle;
  \draw[ink,line width=0.5pt] (9.0,25.0) -- (9.0,32.0) -- (0.0,32.0) -- (0.0,0.0) -- (9.0,0.0) -- (9.0,7.0) -- (10.5,7.0) -- (10.5,0.0) -- (29.0,-0.0) -- (29.0,7.0) -- (30.5,7.0) -- (30.5,-0.0) -- (45.0,-0.0) -- (45.0,7.0) -- (46.5,7.0) -- (46.5,-0.0) -- (48.0,0.0) -- (48.0,32.0) -- (46.5,32.0) -- (46.5,25.0) -- (45.0,25.0) -- (45.0,32.0) -- (30.5,32.0) -- (30.5,25.0) -- (29.0,25.0) -- (29.0,32.0) -- (10.5,32.0) -- (10.5,25.0) -- cycle;
  \draw[ink2,|-|,line width=0.3pt] (0,-3.2) -- (48.0,-3.2) node[midway,below,font=\scriptsize\ttfamily,text=ink] {48};
  \draw[ink2,|-|,line width=0.3pt] (48.0+3.2,0) -- (48.0+3.2,32.0) node[midway,right,font=\scriptsize\ttfamily,text=ink] {32};
  \node[font=\tiny\ttfamily,text=ink,below=-2pt] at (9.75,-1.3) {9\,+\,1½};
  \node[font=\tiny\ttfamily,text=ink,below=-2pt] at (29.75,-1.3) {29\,+\,1½};
  \node[font=\tiny\ttfamily,text=ink,below=-2pt] at (45.75,-1.3) {45\,+\,1½};
  \node[font=\tiny\ttfamily,text=ink,above=-2pt] at (9.75,33.3) {9\,+\,1½};
  \node[font=\tiny\ttfamily,text=ink,above=-2pt] at (29.75,33.3) {29\,+\,1½};
  \node[font=\tiny\ttfamily,text=ink,above=-2pt] at (45.75,33.3) {45\,+\,1½};
  \node[font=\tiny,text=ink2] at (24.0,16.0) {notches 7 in deep};
\end{tikzpicture}\\[1pt]
{\scriptsize\textcolor{ink2}{z\,34½ @ x\,68}}
\end{minipage}
\begin{minipage}[t]{0.33\textwidth}\centering
{\small\bfseries 31 x 32 · notch A}\quad{\footnotesize\textcolor{ink2}{×1}}\\[2pt]
\begin{tikzpicture}[x=0.105cm,y=0.105cm,baseline]
  \fill[ply] (3.0,32.0) -- (3.0,25.0) -- (1.5,25.0) -- (1.5,32.0) -- (0.0,32.0) -- (0.0,0.0) -- (1.5,0.0) -- (1.5,7.0) -- (3.0,7.0) -- (3.0,0.0) -- (31.0,0.0) -- (31.0,1.5) -- (26.5,1.5) -- (26.5,7.0) -- (31.0,7.0) -- (31.0,25.0) -- (26.5,25.0) -- (26.5,30.5) -- (31.0,30.5) -- (31.0,32.0) -- cycle;
  \draw[ink,line width=0.5pt] (3.0,32.0) -- (3.0,25.0) -- (1.5,25.0) -- (1.5,32.0) -- (0.0,32.0) -- (0.0,0.0) -- (1.5,0.0) -- (1.5,7.0) -- (3.0,7.0) -- (3.0,0.0) -- (31.0,0.0) -- (31.0,1.5) -- (26.5,1.5) -- (26.5,7.0) -- (31.0,7.0) -- (31.0,25.0) -- (26.5,25.0) -- (26.5,30.5) -- (31.0,30.5) -- (31.0,32.0) -- cycle;
  \draw[ink2,|-|,line width=0.3pt] (0,-3.2) -- (31.0,-3.2) node[midway,below,font=\scriptsize\ttfamily,text=ink] {31};
  \draw[ink2,|-|,line width=0.3pt] (31.0+3.2,0) -- (31.0+3.2,32.0) node[midway,right,font=\scriptsize\ttfamily,text=ink] {32};
  \node[font=\tiny\ttfamily,text=ink,below=-2pt] at (2.25,-1.3) {1½\,+\,1½};
  \node[font=\tiny\ttfamily,text=ink,below=-2pt] at (28.75,-1.3) {26½\,+\,4½};
  \node[font=\tiny\ttfamily,text=ink,above=-2pt] at (2.25,33.3) {1½\,+\,1½};
  \node[font=\tiny\ttfamily,text=ink,above=-2pt] at (28.75,33.3) {26½\,+\,4½};
  \node[font=\tiny,text=ink2] at (15.5,16.0) {notches 7 in deep};
\end{tikzpicture}\\[1pt]
{\scriptsize\textcolor{ink2}{z\,22½ @ x\,-28}}
\end{minipage}
\begin{minipage}[t]{0.33\textwidth}\centering
{\small\bfseries 24 x 32}\quad{\footnotesize\textcolor{ink2}{×2}}\\[2pt]
\begin{tikzpicture}[x=0.105cm,y=0.105cm,baseline]
  \fill[ply] (24.0,0.0) -- (24.0,32.0) -- (0.0,32.0) -- (0.0,0.0) -- cycle;
  \draw[ink,line width=0.5pt] (24.0,0.0) -- (24.0,32.0) -- (0.0,32.0) -- (0.0,0.0) -- cycle;
  \draw[ink2,|-|,line width=0.3pt] (0,-3.2) -- (24.0,-3.2) node[midway,below,font=\scriptsize\ttfamily,text=ink] {24};
  \draw[ink2,|-|,line width=0.3pt] (24.0+3.2,0) -- (24.0+3.2,32.0) node[midway,right,font=\scriptsize\ttfamily,text=ink] {32};
\end{tikzpicture}\\[1pt]
{\scriptsize\textcolor{ink2}{z\,81½ @ x\,20 · z\,81½ @ x\,75½}}
\end{minipage}
\begin{minipage}[t]{0.33\textwidth}\centering
{\small\bfseries 24 x 32 · notch A}\quad{\footnotesize\textcolor{ink2}{×1}}\\[2pt]
\begin{tikzpicture}[x=0.105cm,y=0.105cm,baseline]
  \fill[ply] (1.5,-0.0) -- (1.5,7.0) -- (3.0,7.0) -- (3.0,-0.0) -- (24.0,0.0) -- (24.0,32.0) -- (3.0,32.0) -- (3.0,25.0) -- (1.5,25.0) -- (1.5,32.0) -- (0.0,32.0) -- (0.0,0.0) -- cycle;
  \draw[ink,line width=0.5pt] (1.5,-0.0) -- (1.5,7.0) -- (3.0,7.0) -- (3.0,-0.0) -- (24.0,0.0) -- (24.0,32.0) -- (3.0,32.0) -- (3.0,25.0) -- (1.5,25.0) -- (1.5,32.0) -- (0.0,32.0) -- (0.0,0.0) -- cycle;
  \draw[ink2,|-|,line width=0.3pt] (0,-3.2) -- (24.0,-3.2) node[midway,below,font=\scriptsize\ttfamily,text=ink] {24};
  \draw[ink2,|-|,line width=0.3pt] (24.0+3.2,0) -- (24.0+3.2,32.0) node[midway,right,font=\scriptsize\ttfamily,text=ink] {32};
  \node[font=\tiny\ttfamily,text=ink,below=-2pt] at (2.25,-1.3) {1½\,+\,1½};
  \node[font=\tiny\ttfamily,text=ink,above=-2pt] at (2.25,33.3) {1½\,+\,1½};
  \node[font=\tiny,text=ink2] at (12.0,16.0) {notches 7 in deep};
\end{tikzpicture}\\[1pt]
{\scriptsize\textcolor{ink2}{z\,69½ @ x\,-28}}
\end{minipage}
\begin{minipage}[t]{0.33\textwidth}\centering
{\small\bfseries 24 x 32 · notch B}\quad{\footnotesize\textcolor{ink2}{×1}}\\[2pt]
\begin{tikzpicture}[x=0.105cm,y=0.105cm,baseline]
  \fill[ply] (6.0,32.0) -- (6.0,25.0) -- (4.5,25.0) -- (4.5,32.0) -- (0.0,32.0) -- (0.0,0.0) -- (4.5,-0.0) -- (4.5,7.0) -- (6.0,7.0) -- (6.0,-0.0) -- (24.0,0.0) -- (24.0,32.0) -- cycle;
  \draw[ink,line width=0.5pt] (6.0,32.0) -- (6.0,25.0) -- (4.5,25.0) -- (4.5,32.0) -- (0.0,32.0) -- (0.0,0.0) -- (4.5,-0.0) -- (4.5,7.0) -- (6.0,7.0) -- (6.0,-0.0) -- (24.0,0.0) -- (24.0,32.0) -- cycle;
  \draw[ink2,|-|,line width=0.3pt] (0,-3.2) -- (24.0,-3.2) node[midway,below,font=\scriptsize\ttfamily,text=ink] {24};
  \draw[ink2,|-|,line width=0.3pt] (24.0+3.2,0) -- (24.0+3.2,32.0) node[midway,right,font=\scriptsize\ttfamily,text=ink] {32};
  \node[font=\tiny\ttfamily,text=ink,below=-2pt] at (5.25,-1.3) {4½\,+\,1½};
  \node[font=\tiny\ttfamily,text=ink,above=-2pt] at (5.25,33.3) {4½\,+\,1½};
  \node[font=\tiny,text=ink2] at (12.0,16.0) {notches 7 in deep};
\end{tikzpicture}\\[1pt]
{\scriptsize\textcolor{ink2}{z\,69½ @ x\,123½}}
\end{minipage}

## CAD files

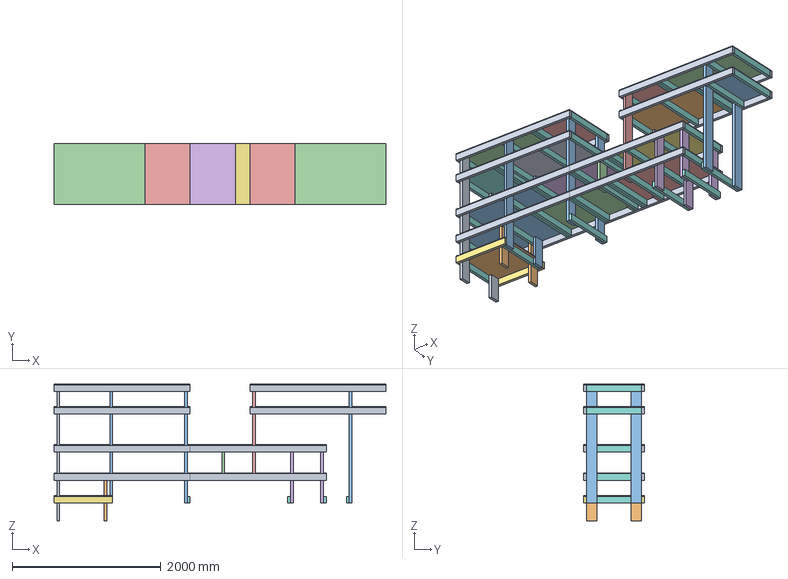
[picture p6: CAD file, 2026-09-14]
bus_mods/jesssullivan/port_side_shelves/CAD/port_side_shelves.step
4457.7 x 812.8 x 1838.3 mm

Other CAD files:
bus_mods/jesssullivan/port_side_shelves/CAD/bus_hybrid_assy.f3d

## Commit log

2026-09-14 Dev (#2)
    * feat(port_side_shelves): add mod with cut list, Bazel/tectonic doc build and nix dev shell
    - Voron-style layout under bus_mods/<creator>/<mod>
    - cut_list.tex: 8 ft stock plan (34x 2x4, 10x 2x6, 5 sheets 3/8 ply), per-board
    cut patterns, sheet layouts, Fusion assembly grouping
    - cutstock.py: exact cutting-stock ILP used for the plan
    - MODULE.bazel pins rules_tectonic 0.2.2 via signed release archive_override
    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
    [bus_hybrid_assy.f3d, port_side_shelves.step]
2026-09-15 docs(port_side_shelves): three-shelf recount at the top, drop handoff notes (#4)
    - variant box: removing the two topmost shelves (z 81.5 decks + z 78 frames)
    buys 7 fewer 2x4s and 1 fewer sheet; 2x6 count unchanged
    - cutstock.py --three-up reproduces the variant plan
    - removed the 'Read before cutting' section and the geometry-source footer
